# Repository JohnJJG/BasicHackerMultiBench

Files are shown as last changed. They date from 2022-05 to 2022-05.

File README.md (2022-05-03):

# Overview
A one stop shop with fixed 5V/12V/24V/USB metered power, adjustable power supply, voltmeter, continuity tester and basic oscilloscope.



# Introduction
It is probably a rite of passage for any hardware hacker to build their own bench supply but with limited desk space I wanted to add a few more standard features that would mean I had everything in one place.

I had a basic list of needs:
1. Current measuring and supply of 5V, 12V, and 24V
2. Variable power supply with current limiting
3. Continuity tester
4. Voltmeter
5. USB Power
6. Oscilloscope – ok, not essential but I had it lying around – sue me.
7. Low cost – not meant to replace the good stuff

Most of the effort has gone into the 3D case for components and power supply. I have tried to do this in a modular fashion in OpenSCAD to allow the configuration to be changed.

The main components of this are DSP3005 Programmable Power Supply (\~$28) and a DSO150 basic oscilloscope (\~$50 for an original). The rest are standard parts like volt/ammeter, voltmeter, binding posts, switch, connectors, dc buck converters, DC to USB

# Before you start
This is an intermediate level project and assumes familiarity with buck converters and soldering.  The space is tight and may require a little adjustment of wires as components are added.  The PSU is an optional part of the build but is fully integrated.  The PSU involves working with mains voltage so do not do this part if you are not use to working with mains voltages (because…death etc).  An alternative is to get a 24V 5A brick supply and add an XT60 female connector.

# Build First
Solder red/black wires to the two LM2596 converters and set the voltage to 12V and 5V (24V input)

Solder red/black wires to the MP1584 converter and set voltage to 9V (24V input) and cover with clear heat shrink

DSO150 – Build the kit and connect the MP1584 converter in place of the 9V jack



Continuity Tester – Solder the buzzer and resistor to the ATTINY85 board and program Solder together the Voltmeter, Continuity Tester and selection switch and cover the attiny with clear heat shrink





# Build Order
Screw in all of the binding posts (6 posts, 2 sockets as in picture) with 1 nut

Screw in the DSO150 (4 short screws for the main board, 2 long for encoder switch and 1 long for the analogue daughter board

Slot in the slide switch, voltmeter

Screw in the 5V LM2596 converter to the side panel beside the DSO150

Slide in the LM2596S Dual USB Power Supply (don’t screw in until all wiring done)

Run wire between the two LM2596S Dual USB and onto the LM2596 converter

Slot in the volt/ammeter to the centre and connect to 5V and posts as per diagram

Slot in the volt/ammeter to the side and connect to on-off-on switch and posts as per diagram

Screw in the 12V LM2596 converter to the side panel below the DPS3005



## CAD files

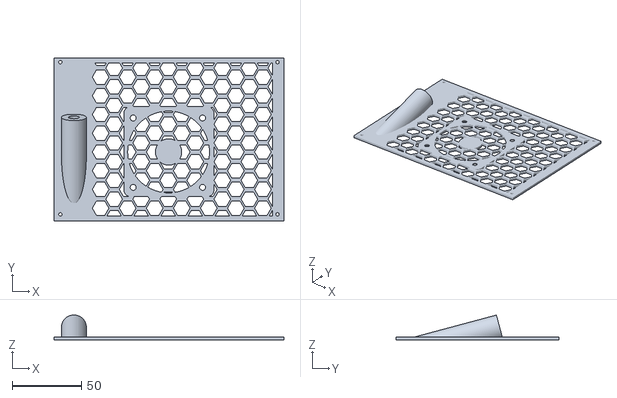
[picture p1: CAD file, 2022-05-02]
stl/MultiBench Back (Jack).stl
165.8 x 117.8 x 17.9

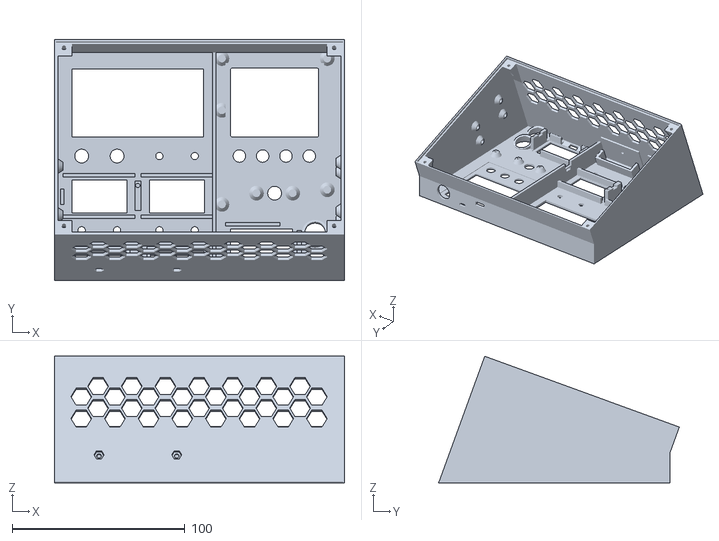
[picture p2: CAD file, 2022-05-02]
stl/MultiBench Face.stl
168.0 x 139.4 x 73.3

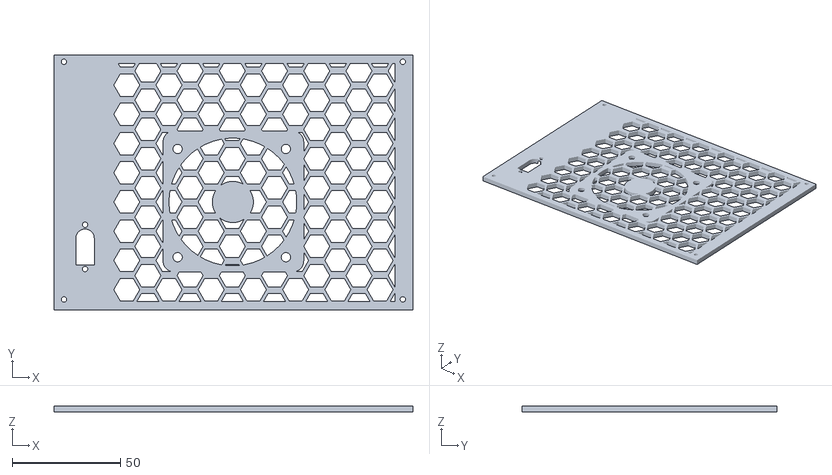
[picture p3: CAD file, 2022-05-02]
stl/MultiBench Back (with PSU).stl
165.8 x 117.8 x 3.00

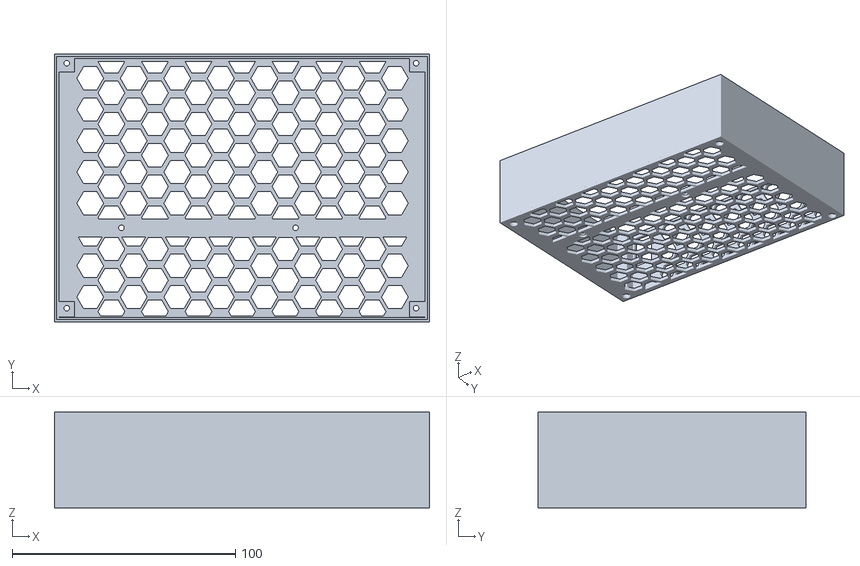
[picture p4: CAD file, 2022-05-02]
stl/MultiBench PSU.stl
168.0 x 120.0 x 43.0

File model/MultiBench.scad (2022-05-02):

/*
Copyright © John Gilmour 2021
This work is licensed under a Creative Commons Attribution-ShareAlike 3.0 Unported License.
http://creativecommons.org/licenses/by-nc-sa/4.0/"><img alt="Creative Commons Licence" style="border-width:0" src="https://i.creativecommons.org/l/by-nc-sa/4.0/88x31.png" /></a><br />This work is licensed under a <a rel="license" href="http://creativecommons.org/licenses/by-nc-sa/4.0/
*/
Show="MultiBench"; // ["MultiBench (Jack)", "MultiBench (PSU)", "Face", "Back (XT60)", "Back (Jack)", "PSU"]

/*[Hidden]*/
HEIGHT=132;
WIDTH=164;
THICK=2;
THICK_BACK=2;
ANGLE=20;

B_DEPTH=40;

$fn=50;

SOLID=true;
CUTOUT=false;

if (Show=="MultiBench (Jack)") {
  rotate ([90,0,270]) translate ([-WIDTH/2,0,-45]) Combined("Jack");
}
else if (Show=="MultiBench (PSU)") {
  rotate ([90,0,270]) translate ([-WIDTH/2,0,-45]) Combined("PSU");
}
else if (Show=="Face") {
  MultiBench();
}
else if (Show=="Back (XT60)") {
  difference() {
    translate([1,-2,0]) Back("XT60");
  }
}
else if (Show=="Back (Jack)") {
  difference() {
    translate([1,-2,0]) Back("Jack");
  }
}
else if (Show=="PSU") {
  translate([THICK,-1,B_DEPTH+THICK]) mirror([0,0,1]) PSU();
}
module Combined(sInput) {
    rotate ([20,0,0]) MultiBench();
    if (sInput=="PSU")
      color ("DeepSkyBlue",1.0) translate([WIDTH,-.9,79]) mirror([1,0,0]) PSU();
    color ("Green",1.0) translate([WIDTH-0.4,-1,77]) mirror([1,0,0]) mirror([0,0,1]) Back(sInput);
}

module Back(sInput) {
  difference () {
    union() {
      difference() {
        union() {
          translate([-1.1,2.1,0]) cube([WIDTH+2-0.2,HEIGHT-14-0.2,THICK_BACK]);
          if (sInput=="Jack")
            translate([6.5,21,0]) Jack21_55(SOLID);
        }
        if (sInput=="XT60")
          translate([6.5,21,0]) XT60();
        else
          translate([6.5,21,0]) Jack21_55(CUTOUT);
          

        //hexagonal air vent
        translate([13,-2,-1]) for (xPos=[1:7]) {
          for (yPos=[0:9]) {
            translate([xPos*19.5,yPos*13.5,-1]) cylinder(h=10,r=6, $fn=6);
            translate([(xPos*19.5)+9.75,(yPos*13.5)+6.5,-1]) cylinder(h=10,r=6, $fn=6);
          }
        }
      }
      translate([51,21.5,0]) Fan60(SOLID);
      //need to trim the hexagonal air vents
      difference() {
        translate([25,2.1,0]) cube([WIDTH-24.3,HEIGHT-14-0.2,THICK_BACK]);
        translate([10,6,-1]) cube([WIDTH-17.5,HEIGHT-22,6]);
      }
    }
    translate([51,21.5,0]) Fan60(CUTOUT);

    //corner holes
    for (xPos=[WIDTH-4, 3.5]) {
      translate([xPos,116.75,-3]) cylinder(h=B_DEPTH+THICK+4,r=1.25);
      translate([xPos,7,-3]) cylinder(h=B_DEPTH+THICK+4,r=1.25);
    }
  }
}

module PSU(){
  difference() {
    union() {
      difference() {
        //box
        translate([-THICK,0.85,-1]) cube([WIDTH+(2*THICK),120,B_DEPTH+THICK+1]);
        //Lip
        translate([-1,1.85,-2]) cube([WIDTH+2,118,2]);
        //hollow box
        translate([0,0.85+THICK,-THICK-2]) cube([WIDTH,120-(2*THICK),B_DEPTH+(2*THICK)]);
        //mains switch hole
        translate([8,118,3]) cube([13,4,19.5]);
        //mains cable
        translate([-3,17,30]) rotate([0,90,0]) cylinder(h=10,r=5);
        
        //hexagonal back air vent
        translate([-5.5,-2,0]) for (xPos=[1:8]) {
          for (yPos=[0:8]) {
            translate([xPos*19.5,yPos*14,B_DEPTH-0.01]) cylinder(h=10,r=6, $fn=6);
            if ((xPos <8) && (yPos<9)) {
              translate([(xPos*19.5)+9.5,(yPos*14)+7.5,B_DEPTH-.01]) cylinder(h=10,r=6, $fn=6);
            }
          }
        }
        //hexagonal top air vent
        translate([-5.5,HEIGHT+36-0.155,-7.5]) rotate ([90,0,0]) for (xPos=[2:8]) {
          for (yPos=[0:3]) {
              translate([xPos*19.5,yPos*14,B_DEPTH-1]) cylinder(h=10,r=6, $fn=6);
            if (xPos<8)
              translate([(xPos*19.5)+9.5,(yPos*14)+7.5,B_DEPTH-1]) cylinder(h=10,r=6, $fn=6);
          }
        }
      }
      //hexagonal back air vent boundry frame
      difference() {
        translate([-THICK,0.85,B_DEPTH]) cube([WIDTH+(2*THICK),120,THICK]);
        translate([-THICK,3.5,B_DEPTH-1]) cube([WIDTH+(2*THICK),114,THICK+2]);
      }
      //hexagonal top air vent boundry frame
      difference() {
        union() {
          translate([21,HEIGHT-11.15,0]) rotate([90,0,0]) cube([WIDTH+THICK-21,B_DEPTH+THICK,THICK]);
          translate([25,HEIGHT-11.15,-1]) rotate([90,0,0]) cube([WIDTH+THICK-25,1,1]);
          translate([0,HEIGHT-11.15,38]) rotate([90,0,0]) cube([29,4,THICK]);
        }
        translate([27.5,HEIGHT-10,1]) rotate([90,0,0]) cube([WIDTH+THICK-37,39,THICK+2]);
      }
      //screw posts and holes
      difference() {
        union() {
          //corner screw posts
          for (xPos=[WIDTH-7, 0]) {
            translate([xPos,112.8,0]) cube([7,7,B_DEPTH+THICK]);
            translate([xPos,3,0]) cube([7,7,B_DEPTH+THICK]);
          }
          //back screw plate
          translate([0,39,B_DEPTH]) cube([WIDTH,8,THICK]);
        }
      }
    }
    // corner screw holes
    for (xPos=[WIDTH-4, 3.5]) {
      translate([xPos,116.75,-3]) cylinder(h=B_DEPTH+THICK+4,r=1.25);
      translate([xPos,116.75,3]) cylinder(h=B_DEPTH+THICK,r=2.5);
      translate([xPos,7,-3]) cylinder(h=B_DEPTH+THICK+4,r=1.25);
      translate([xPos,7,3]) cylinder(h=B_DEPTH+THICK,r=2.5);
    }
    //scew holes through the back
    for (xPos=[WIDTH-58, WIDTH-136]) {
      translate([xPos,43,B_DEPTH-1]) cylinder(h=THICK+2,d=2.5);
      translate([xPos,43,B_DEPTH+1]) cylinder(h=THICK+20,d=5);
    }
  }
}

module MultiBench(){
  difference(){
    union() {
      color ("White",1.0) Frame(SOLID); // add the solid psrt for holding the components
      color ("Red",1.0) Components(SOLID); // add the solid psrt for holding the components
    }

    color ("Red",1.0) Components(CUTOUT); //remove any material needed to house the components
    color ("White",1.0) Frame(CUTOUT);
  }
  difference () {
    union () {
      for (xPos=[-1, WIDTH-8]) {
        hull() {
          translate([xPos,130,33.5]) rotate ([-ANGLE,0,0]) cube([9,8,.1]);
          translate([xPos,132.3,18]) rotate ([-ANGLE+90,0,0]) cube([9,9,.1]);
        }
        hull() {
          translate([xPos,27,71]) rotate ([-ANGLE,0,0]) cube([9,8,.1]);
          translate([xPos,20,50]) rotate ([-ANGLE+90,0,0]) cube([9,9,.1]);
        }
      }
    }
    // corner screw holes
    for (xPos=[3.5, WIDTH-4]) {
      translate([xPos,130.5,20])  rotate ([-ANGLE,0,0]) cylinder(h=20,r=1.25);
      translate([xPos,25.7,53])  rotate ([-ANGLE,0,0]) cylinder(h=20,r=1.25);
    }
    //rotate ([-ANGLE,0,0]) translate([-(2*THICK),0,0]) linear_extrude(height = 73) square([WIDTH+(4*THICK), HEIGHT]);
  }
}

module Components(bProcess) {
  translate([90,HEIGHT,0]) Osc(bProcess); // referenced from inside top left
  translate([1.5,38,0]) Meter(bProcess,2);
  translate([95.5,9.5,0]) Meter(bProcess,1,iDigits=3);
  translate([8,83,-1]) Dsp150(bProcess);
  translate([6,3,5]) rotate([-ANGLE,0,0]) Usb(bProcess);
  translate([51,3,5]) rotate([-ANGLE,0,0]) Usb(bProcess);
  #translate([0,30,40]) rotate ([90,ANGLE,90]) Buck(bProcess);  // referenced bottom left
  translate([WIDTH,35,48]) rotate ([-90,ANGLE,90]) Buck(bProcess);  // referenced bottom left
  plugs_jack(bProcess); // 2.1mm barrel jacks
  plugs_post(bProcess); // binding posts
  plugs_flush(bProcess); // probe sockets
  translate ([108,2.5,1]) rotate([-ANGLE,0,0]) SlideSwitch(bProcess);
  translate ([0.5,47,0]) rotate([-ANGLE+90,0,0]) Vent(bProcess);
}
module Frame(bProcess){
  if (bProcess==SOLID) {
    //face, base, top, left side and right side
    translate([0,0,0]) linear_extrude(height = 2) square([WIDTH, HEIGHT]);
    rotate ([-ANGLE,0,0]) translate([0,0,.7]) linear_extrude(height = 165) square([WIDTH, THICK]);
    translate([-THICK,HEIGHT,0]) linear_extrude(height = 100) square([WIDTH+(2*THICK), THICK]);
    rotate ([-ANGLE,0,0]) translate([-(THICK),0,62]) linear_extrude(height = 100) square([WIDTH+(2*THICK), HEIGHT-12]);
    translate([WIDTH,0,0]) linear_extrude(height = 100) square([THICK, HEIGHT+THICK]);
    translate([-THICK,0,0]) linear_extrude(height = 100) square([THICK, HEIGHT+THICK]);
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

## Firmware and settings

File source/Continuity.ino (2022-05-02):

/* Continuity Tester
 
   AtTiny85 DigiSpark version John Gilmour 15 Sept 2021
   Original: http://www.technoblogy.com/show?1YON (David Johnson-Davies Nov 2017)

   This a simpler build than David's, uses a USB Programmable board (Digispark)
   with one resistor and active buzzer.  A passive buzzer is a problem on P4 for
   this board so but an active buzzer simplifies programming, costs only  ~$0.50
   and can be attached to Pin 2

   There are plenty of  guides on programming a DigiSpark board (or clones)
   e.g. http://digistump.com/wiki/digispark/tutorials/connecting
   
   CC BY 4.0
   Licensed under a Creative Commons Attribution 4.0 International license: 
   http://creativecommons.org/licenses/by/4.0/
*/

const int Reference = 0;                  // AIN0
const int Probe = 1;                      // AIN1
const int SPEAKER_PIN = 2;
const int P3 = 3;
const int P4 = 4;

void setup () {
  pinMode(Reference, INPUT_PULLUP); // Reference Pin AIN0
  pinMode(Probe, INPUT_PULLUP);     // Reference PIN AIN1
  pinMode(SPEAKER_PIN, OUTPUT);     // Speaker Pin P2
  pinMode(P3, OUTPUT);              // Unused P4 (Dont leave floating)
  pinMode(P4, OUTPUT);              // Unused P4 (Dont leave floating) 
}

//Apart from pin setup just one line of code, buzz when >50ohm
void loop() {
  digitalWrite(SPEAKER_PIN, ACSR>>ACO & 1);  // Analog Comparator result is bit 5 of the ACSR register (If (AIN+) > (AIN-)  ACO = 1)
}
